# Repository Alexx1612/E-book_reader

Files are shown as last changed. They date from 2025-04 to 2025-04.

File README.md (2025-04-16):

## OPENBOOK E-BOOK READER
OpenBook – Proiect TSC 2025
OpenBook este un prototip de eBook reader open-source, dezvoltat în jurul microcontrolerului ESP32-C6. Dispozitivul este echipat cu un afișaj E-Ink, baterie Li-Po, încărcare prin USB-C, slot pentru card microSD și o serie de senzori de mediu. Proiectul a presupus realizarea completă a schemei electrice, proiectarea plăcii PCB, modelarea 3D și generarea fișierelor pentru fabricație.

## Diagrama bloc
Diagrama

### Caracteristici Cheie
- **Alimentare prin USB-C**  
  Permite programarea ușoară și încărcarea bateriei, asigurând o integrare simplificată cu sursa de alimentare.
- **Microcontroller ESP32-C6**  
  Dispune de un nucleu RISC-V, Wi-Fi 6, BLE și 8MB memorie flash internă pentru aplicații complexe și conectivitate modernă.
- **Senzori Integrați**  
  - **BME688:** Măsoară temperatura, umiditatea, presiunea și concentrațiile de gaze.  
  - **DS3231:** Modul RTC de înaltă precizie, care menține ceasul de timp real chiar și în absența alimentării principale.
- **Stocare Suplimentară**  
  - **Card SD (SPI):** Permite stocarea locală a e-book-urilor și datelor adiționale.  
  - **Memorie NOR Flash (W25Q512):** Oferă spațiu suplimentar de stocare prin interfața SPI.
- **Afișaj E-Paper**  
  Realizează afișajul e-book-urilor cu consum ultra-redus, prin actualizări doar la nevoie.
- **Monitorizare Baterie**  
  Modulul MAX17048 monitorizează nivelul de încărcare al bateriei, contribuind la gestionarea eficientă a consumului de energie.

## Bill of materials (BOM)

| Component | Supplier Link | Datasheet |
|---|---|---|
| XC6220A331MR-G | [Model](https://componentsearchengine.com/part-view/XC6220A331MR-G/Torex) | [Datasheet](https://product.torexsemi.com/system/files/series/xc6220.pdf) |
| W25Q512JVEIQ | [Model](https://www.snapeda.com/parts/W25Q512JVEIQ/Winbond+Electronics/view-part/?ref=eda) | [Datasheet](https://www.winbond.com/resource-files/W25Q512JV%20SPI%20RevB%2006252019%20KMS.pdf) |
| USBLC6-2SC6Y | [Model](https://www.snapeda.com/parts/USBLC6-2SC6Y/STMicroelectronics/view-part/?welcome=home&ref=eda) | [Datasheet](https://www.snapeda.com/parts/USBLC6-2SC6Y/STMicroelectronics/datasheet/) |
| USB4110-GF-A | [Model](https://componentsearchengine.com/part-view/USB4110-GF-A/GCT%20(GLOBAL%20CONNECTOR%20TECHNOLOGY)) | [Datasheet](https://gct.co/files/drawings/usb4110.pdf) |
| SJ | [Model](https://grabcad.com/library/solder-jumpers-1) | [Datasheet]() |
| SI1308EDL-T1-GE3 MOSFET | [Model](https://www.snapeda.com/parts/SI1308EDL-T1-GE3/Vishay+Siliconix/view-part/?welcome=home&ref=eda) | [Datasheet](https://www.snapeda.com/parts/SI1308EDL-T1-GE3/Vishay%20Siliconix/datasheet/) |
| Resistor 0402 | [Model](https://grabcad.com/library/resistor-0402-1) | [Datasheet](https://www.yageo.com/upload/media/product/products/datasheet/rchip/PYu-RC_Group_51_RoHS_L_12.pdf) |
| RCL CPOL 3528 | [Model](https://www.snapeda.com/parts/CPH3225A/Seiko+Instruments/view-part/?ref=eda) | [Datasheet](https://s3.amazonaws.com/snapeda/datasheet/TAJB475K025RNJ_AVX.pdf) |
| QWIIC Connector | [Model](https://www.snapeda.com/parts/PRT-14417/SparkFun/view-part/) | [Datasheet](https://www.snapeda.com/parts/PRT-14417/SparkFun%20Electronics/datasheet/) |
| PGB1010603MR | [Model](https://www.snapeda.com/parts/PGB1010603MR/Littelfuse/view-part/?ref=eda) | [Datasheet](https://www.snapeda.com/parts/PGB1010603MR/Littelfuse%20Inc./datasheet/) |
| MBR0530 Schottky Diode | [Model](https://www.snapeda.com/parts/MBR0530/Onsemi/view-part/?ref=snap) | [Datasheet](https://www.snapeda.com/parts/MBR0530/ON%20Semiconductor/datasheet/) |
| MAX17048G+T10 | [Model](https://www.snapeda.com/parts/MAX17048G+T10/Analog+Devices/view-part/?ref=eda) | [Datasheet](https://www.snapeda.com/parts/MAX17048G+T10/Analog%20Devices/datasheet/) |
| LED Chip 0603 | [Model](https://www.snapeda.com/parts/KP-1608SURCK/Kingbright/view-part/?ref=search&t=LED%200603) | [Datasheet](https://www.snapeda.com/parts/KP-1608SURCK/Kingbright/datasheet/) |
| FH34SRJ-24S-0.5SH | [Model](https://ro.mouser.com/ProductDetail/Hirose-Connector/FH34SRJ-24S-0.5SH99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) | [Datasheet](https://www.snapeda.com/parts/FH34SRJ-24S-0.5SH(99)/Hirose%20Connector/datasheet/) |
| ESP32C6 WROOM-1-N8 | [Model](https://www.snapeda.com/parts/ESP32-C6-WROOM-1-N8/Espressif+Systems/view-part/?ref=eda) | [Datasheet](https://www.snapeda.com/parts/ESP32-C6-WROOM-1-N8/Espressif%20Systems/datasheet/) |
| ESP32C6 Varistor 1812 | [Model]() | [Datasheet]() |
| ESP32 WROVER MCP73831 Power Management | [Model](https://www.snapeda.com/parts/BME680/Bosch/view-part/?welcome=home) | [Datasheet](https://www.snapeda.com/parts/MCP73831T-2ACI/OT/Microchip/datasheet/) |
| ESP32 WROVER BME680 Sensor | [Model](https://www.snapeda.com/parts/BME680/Bosch/view-part/?welcome=home) | [Datasheet](https://www.bosch-sensortec.com/media/boschsensortec/downloads/datasheets/bst-bme680-ds001.pdf) |
| ESP32 WROVER 0805 Capacitor | [Model]() | [Datasheet]() |
| DS3231SN | [Model](https://www.snapeda.com/parts/DS3231SN%23/Analog+Devices/view-part/?ref=eda) | [Datasheet](https://www.snapeda.com/parts/DS3231SN%23/Analog%20Devices/datasheet/) |
| Custom Button | [Model](https://industry.panasonic.com/global/en/products/control/switch/light-touch/number/evqpuj02k) | [Datasheet](https://industry.panasonic.com/global/en/downloads?tab=catalog&small_g_cd=203&part_no=EVQPUJ02K) |
| CPH3225A | [Model](https://www.snapeda.com/parts/CPH3225A/Seiko+Instruments/view-part/?ref=snap) | [Datasheet](https://www.snapeda.com/parts/CPH3225A/Seiko%20Instruments/datasheet/) |
| Capacitor 0402 | [Model](https://ro.mouser.com/c/passive-components/capacitors/ceramic-capacitors/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) | [Datasheet](https://componentsearchengine.com/Datasheets/2/CC0402MRX5R5BB106.pdf) |
| BD5229G-TR | [Model](https://componentsearchengine.com/part-view/BD5229G-TR/ROHM%20Semiconductor) | [Datasheet](https://fscdn.rohm.com/en/products/databook/datasheet/ic/power/voltage_detector/bd52xxg-e.pdf) |
| 744043680 | [Model](https://ro.mouser.com/ProductDetail/Wurth-Elektronik/744043680?qs=PGXP4M47uW6VkZq%252BkzjrHA%3D%3D) | [Datasheet](https://www.we-online.com/components/products/datasheet/744043680.pdf) |
| 112A-TAAR-R03 | [Model](https://store.comet.srl.ro/Catalogue/Product/43497/) | [Datasheet](https://www.snapeda.com/parts/112A-TAAR-R03/Attend/datasheet/) |

## Consum

| Component | Current Draw (mA) | Voltage (V) | Power (mW) |
|---|---|---|---|
| ESP32-C6 (Wi-Fi active) | 200 | 3.3 | 660 |
| E-Paper Display (Updating) | 40 | 3.3 | 132 |
| BME688 Sensor (Measuring) | 3.1 | 3.3 | 10.23 |
| RTC Module (Active) | 0.15 | 3.3 | 0.495 |
| SD Card (Active) | 50 | 3.3 | 165 |
| Externar NOR Flash | 25 | 3.3 | 82.5 |
| **Total Estimated Power Consumption** | ~318.5 mA | 3.3 | 1050.72 |

### Arhitectura Hardware
- **Alimentare și Protecție:**  
  Sistemul beneficiază de alimentare prin USB-C și include protecții ESD (varistori, diodă TVS) pentru siguranța componentelor. Circuitul de încărcare Li-Po (MCP73831) și regulatorul LDO asigură o tensiune stabilă de 3.3V.
- **Conectivitate și Interfețe:**  
  Microcontrollerul ESP32-C6-WROOM-1 acționează ca nucleu central, conectând diferite periferice prin:
  - **SPI:** Utilizat pentru afișajul E-Paper, Cardul SD și memoria NOR Flash.  
  - **I2C:** Folosit pentru senzorii BME688 și DS3231, precum și pentru monitorizarea bateriei.  
  - **GPIO:** Gestionarea butoanelor de control (RESET, BOOT) și alte funcții digitale.

### Mapare Pini ESP32-C6
| Component | ESP32-C6 Pin(s) | Interface | Scop |
|---|---|---|---|
| **E-Paper Display** | IO7 (MOSI), IO6 (SCK), IO10 (CS), IO5 (DC), IO23 (RST), IO3 (BUSY) | SPI | Transferă datele imaginii către afișaj și controlează starea acestuia. |
| **Battery Monitoring (MAX17048)** | IO21 (SDA), IO22 (SCL) | I2C | Monitorizează tensiunea bateriei și starea de încărcare pentru un management energetic eficient. |
| **USB-C Connection** | GPIOs prin circuit de protecție și reglementare | USB | Furnizează alimentarea și permite programarea ESP32-C6. 
| **MicroSD Card** | IO7 (MOSI), IO6 (SCK), IO4 (SS_SD), IO2 (MISO) | SPI | Permite stocarea și accesarea fișierelor de e-book. |
| **Environmental Sensor (BME688)** | IO21 (SDA), IO22 (SCL) | I2C | Măsoară temperatura, umiditatea, presiunea și calitatea aerului. |
| **RTC Module (DS3231)** | IO21 (SDA), IO22 (SCL), IO18 (RST), IO1 (32KHz), IO0 (INT_RTC) | I2C | Menține ceasul de timp real în mod precis, chiar și în absența alimentării principale. |
| **External NOR Flash** | IO11 (CS), IO6 (SCK), IO2 (MISO), IO7 (MOSI) | SPI | Oferă stocare suplimentară pentru datele aplicațiilor și firmware. |
| **Control Buttons** | IO9 (BOOT), IO15 (CHANGE), EN (RESET) | GPIO | Permite interacțiunea utilizatorului prin funcții de boot, reset și alte comenzi digitale.| 

## Observații Suplimentare

- Traseele de alimentare au o lățime de 0.3 mm, iar traseele de semnal sunt proiectate cu o lățime de 0.15 mm, pentru a asigura o transmisie clară și o pierdere minimă de semnal.
- PCB-ul are o grosime de 1 mm și include planuri de masă pe ambele straturi, pentru a optimiza împământarea și a reduce interferențele electromagnetice.
- Conectorii, afișajul E-Paper și bateria au fost integrate în modelul 3D, iar acestea au fost testate riguros pentru a asigura o potrivire perfectă în carcasă.
- Carcasa a fost importată și aliniată cu placa pentru a obține render-uri vizuale realiste, facilitând astfel evaluarea designului final.
- Toate fișierele de proiect au fost verificate prin ERC (Electrical Rules Check) și DRC (Design Rules Check) pentru a asigura conformitatea cu standardele de proiectare și a elimina eventualele erori de fabricație.

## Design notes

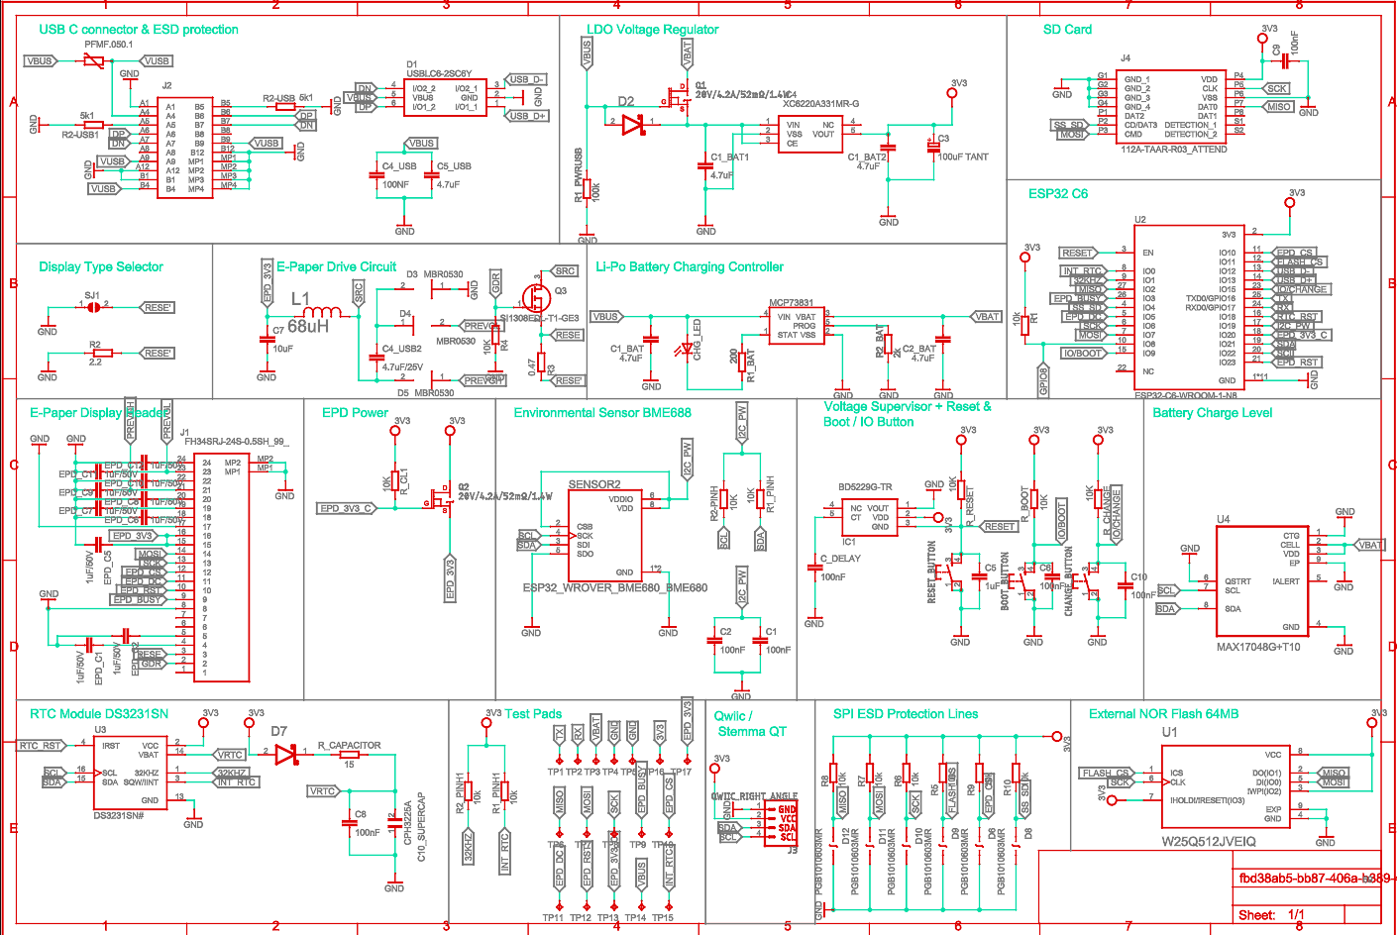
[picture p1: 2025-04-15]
Images/Schematic.png

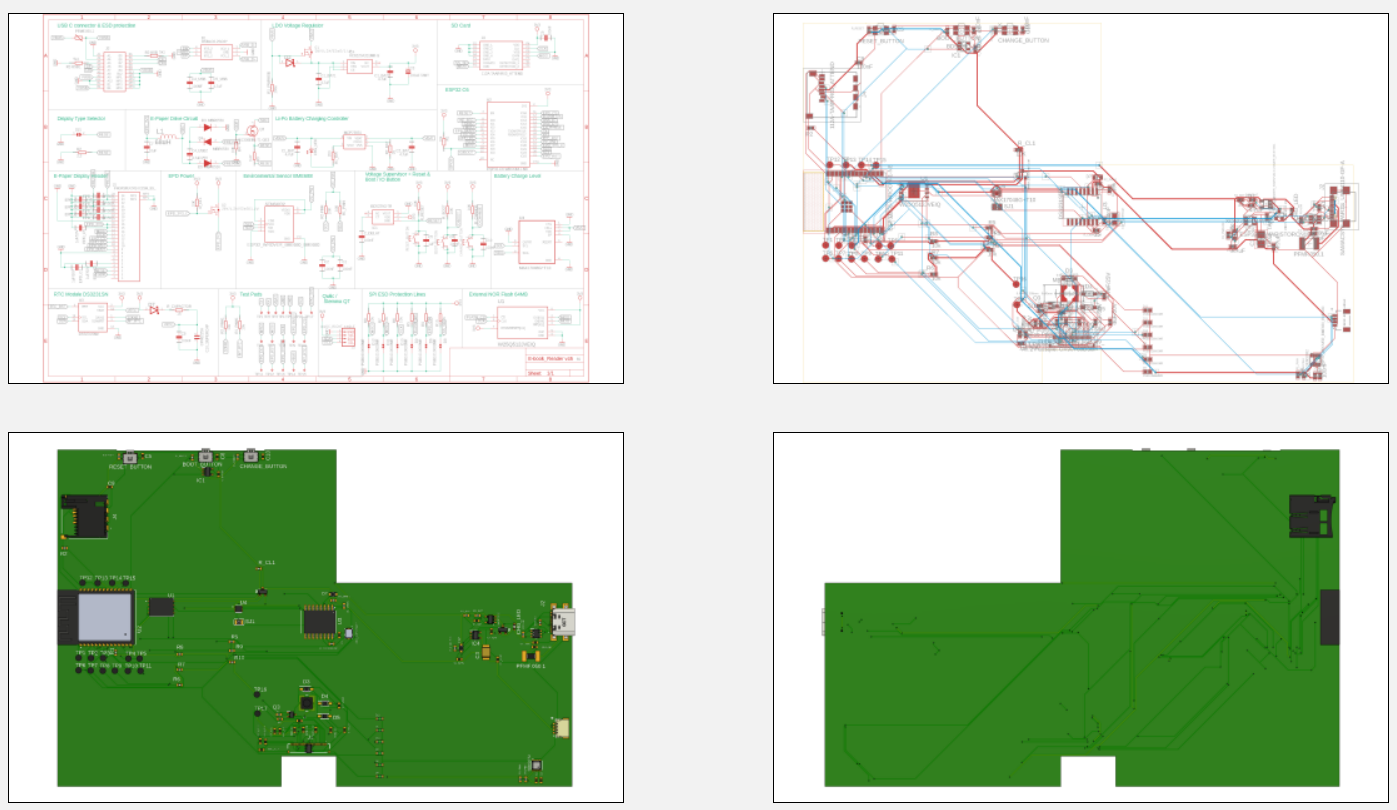
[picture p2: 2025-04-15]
Images/project.png

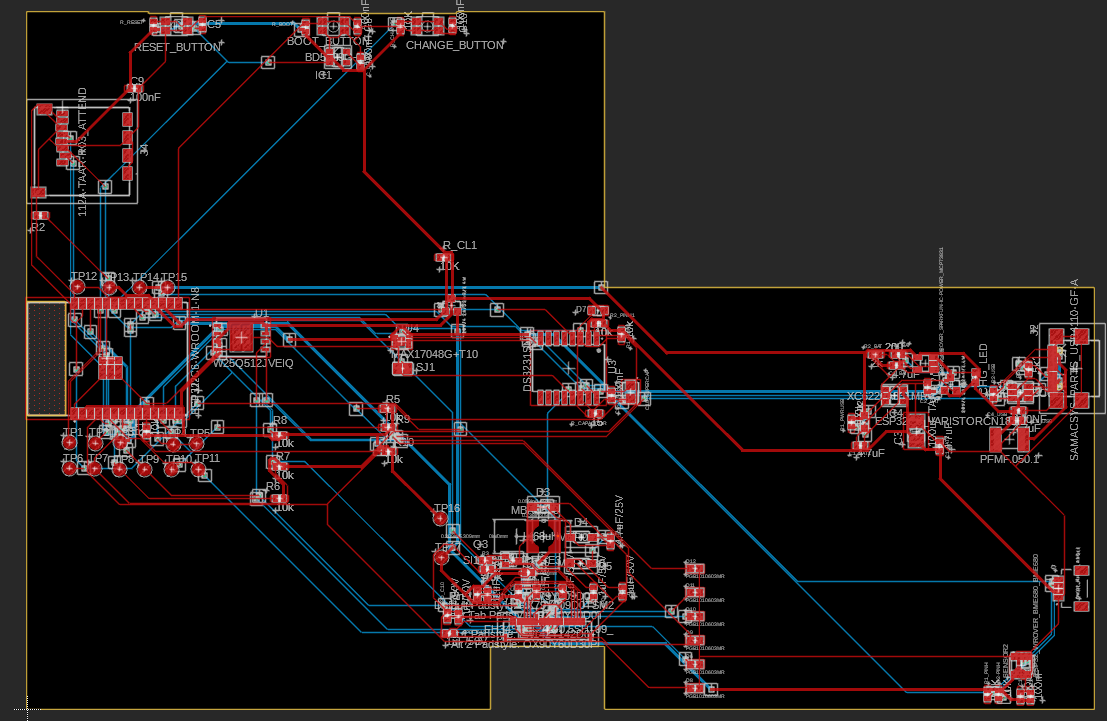
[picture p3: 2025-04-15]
Images/PCB_2D.png

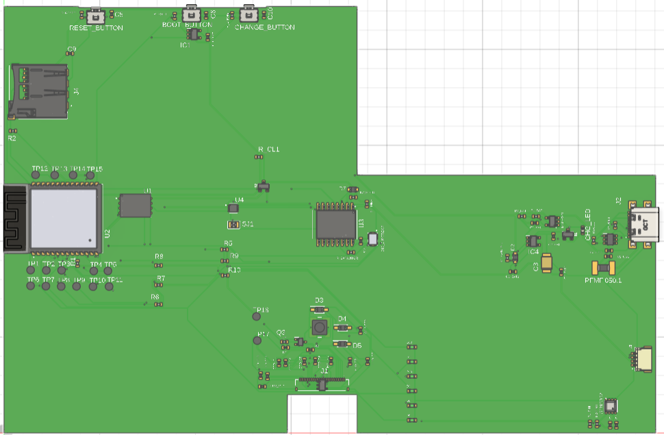
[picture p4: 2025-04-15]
Images/PCB_3D_top.png

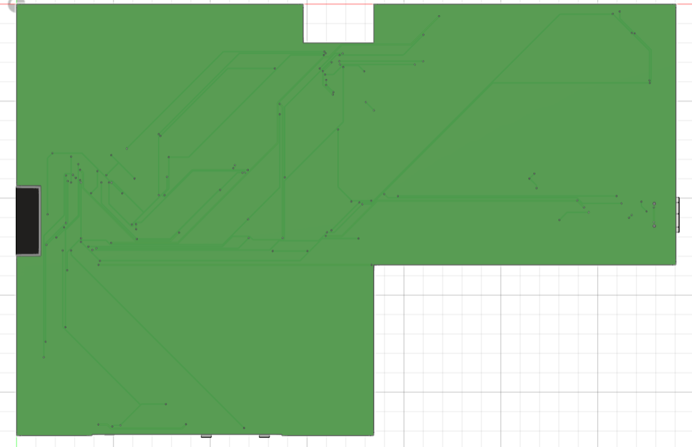
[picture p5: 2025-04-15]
Images/PCB_3D_bottom.png

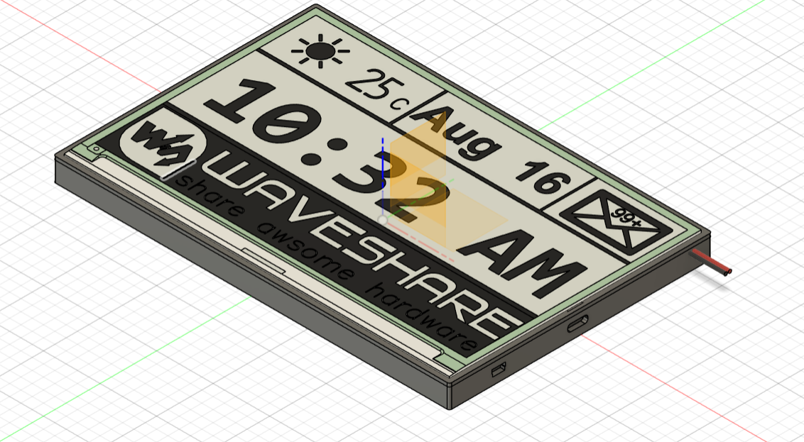
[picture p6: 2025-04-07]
Images/PCB_3D_enclosed.png

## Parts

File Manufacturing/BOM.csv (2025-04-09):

Qty | Value | Device | Package | Parts | Description | ARROW_PART_NUMBER | ARROW_PRICE-STOCK | AVAILABILITY | CENTROID_NOT_SPECIFIED | CHECK_PRICES | COPYRIGHT | DATASHEET | DESCRIPTION | DIGIKEY_DESCRIPTION | DIGIKEY_PART_NUMBER | HEIGHT | LEAD_FREE | MANUFACTURER_NAME | MANUFACTURER_PART_NUMBER | MF | MFR_NAME | MOUSER_PART_NUMBER | MOUSER_PRICE-STOCK | MOUSER_TESTING_PART_NUMBER | MOUSER_TESTING_PRICE-STOCK | MP | MPN | PACKAGE | POPULARITY | PREFIX | PRICE | PROD_ID | PURCHASE-URL | ROHS | SNAPEDA_LINK | SPICEMODEL | SPICEPREFIX | TEMPERATURE_RANGE_HIGH | TEMPERATURE_RANGE_LOW | TP_SIGNAL_NAME | VALUE
1 |  | ADAFRUIT_LEDCHIP-LED0603 | ADAFRUIT_CHIP-LED0603 | CHG_LED | LED
1 |  | SJ | SJ | SJ1 | SMD solder JUMPER |  |  |  |  |  |  |  |  |  |  |  |  |  |  |  |  |  |  |  |  |  |  |  | 3
1 | 0.47 | ESP32_WROVER_EAGLE-LTSPICE_RR0402 | ESP32_WROVER_EAGLE-LTSPICE_R0402 | R3 | RESISTOR, European symbol |  |  |  |  |  |  |  |  |  |  |  |  |  |  |  |  |  |  |  |  |  |  |  |  |  |  |  |  |  |  | NONE | R
1 | 100NF | EAGLE-LTSPICE_CC0402 | EAGLE-LTSPICE_C0402 | C4_USB | CAPACITOR, European symbol |  |  |  |  |  |  |  |  |  |  |  |  |  |  |  |  |  |  |  |  |  |  |  |  |  |  |  |  |  |  | NONE | C
1 | 100k | ESP32_WROVER_EAGLE-LTSPICE_RR0402 | ESP32_WROVER_EAGLE-LTSPICE_R0402 | R1_PWRUSB | RESISTOR, European symbol |  |  |  |  |  |  |  |  |  |  |  |  |  |  |  |  |  |  |  |  |  |  |  |  |  |  |  |  |  |  | NONE | R
7 | 100nF | EAGLE-LTSPICE_CC0402 | EAGLE-LTSPICE_C0402 | C1, C2, C6, C8, C9, C10, C_DELAY | CAPACITOR, European symbol |  |  |  |  |  |  |  |  |  |  |  |  |  |  |  |  |  |  |  |  |  |  |  |  |  |  |  |  |  |  | NONE | C
1 | 100uF TANT | RCL_CPOL-EUCT3528 | RCL_CT3528 | C3 | POLARIZED CAPACITOR, European symbol |  |  |  |  |  |  |  |  |  |  |  |  |  |  |  |  |  |  |  |  |  |  |  | 0 |  |  |  |  |  |  |  | C
7 | 10K | ESP32_WROVER_EAGLE-LTSPICE_RR0402 | ESP32_WROVER_EAGLE-LTSPICE_R0402 | R1_PINH, R2-PINH, R4, R_BOOT, R_CHANGE, R_CL1, R_RESET | RESISTOR, European symbol |  |  |  |  |  |  |  |  |  |  |  |  |  |  |  |  |  |  |  |  |  |  |  |  |  |  |  |  |  |  | NONE | R
9 | 10k | ESP32_WROVER_EAGLE-LTSPICE_RR0402 | ESP32_WROVER_EAGLE-LTSPICE_R0402 | R1_PINH1, R2_PINH1, R2_PINH5, R5, R6, R7, R8, R9, R10 | RESISTOR, European symbol |  |  |  |  |  |  |  |  |  |  |  |  |  |  |  |  |  |  |  |  |  |  |  |  |  |  |  |  |  |  | NONE | R
1 | 10uF | EAGLE-LTSPICE_CC0402 | EAGLE-LTSPICE_C0402 | C7 | CAPACITOR, European symbol |  |  |  |  |  |  |  |  |  |  |  |  |  |  |  |  |  |  |  |  |  |  |  |  |  |  |  |  |  |  | NONE | C
1 | 112A-TAAR-R03_ATTEND | 112A-TAAR-R03_ATTEND | 112ATAARR03ATTEND | J4 | Micro SD Card Socket, Push-Push Type, Top Mount, SMT, H=1.83mm, 10u |  |  |  |  |  |  |  | Micro SD Card Socket | Push-Push Type | Top Mount | SMT | H=1.83mm | 10u |  |  | 1.9mm |  | ATTEND | 112A-TAAR-R03 ATTEND
1 | 15 | ESP32_WROVER_EAGLE-LTSPICE_RR0402 | ESP32_WROVER_EAGLE-LTSPICE_R0402 | R_CAPACITOR | RESISTOR, European symbol |  |  |  |  |  |  |  |  |  |  |  |  |  |  |  |  |  |  |  |  |  |  |  |  |  |  |  |  |  |  | NONE | R
1 | 1uF | EAGLE-LTSPICE_CC0402 | EAGLE-LTSPICE_C0402 | C5 | CAPACITOR, European symbol |  |  |  |  |  |  |  |  |  |  |  |  |  |  |  |  |  |  |  |  |  |  |  |  |  |  |  |  |  |  | NONE | C
10 | 1uF/50V | EAGLE-LTSPICE_CC0402 | EAGLE-LTSPICE_C0402 | EPD_C1, EPD_C2, EPD_C5, EPD_C6, EPD_C7, EPD_C8, EPD_C9, EPD_C10, EPD_C11, EPD_C12 | CAPACITOR, European symbol |  |  |  |  |  |  |  |  |  |  |  |  |  |  |  |  |  |  |  |  |  |  |  |  |  |  |  |  |  |  | NONE | C
1 | 2.2 | ESP32_WROVER_EAGLE-LTSPICE_RR0402 | ESP32_WROVER_EAGLE-LTSPICE_R0402 | R2 | RESISTOR, European symbol |  |  |  |  |  |  |  |  |  |  |  |  |  |  |  |  |  |  |  |  |  |  |  |  |  |  |  |  |  |  | NONE | R
1 | 200 | ESP32_WROVER_EAGLE-LTSPICE_RR0402 | ESP32_WROVER_EAGLE-LTSPICE_R0402 | R1_BAT | RESISTOR, European symbol |  |  |  |  |  |  |  |  |  |  |  |  |  |  |  |  |  |  |  |  |  |  |  |  |  |  |  |  |  |  | NONE | R
2 | 20V/4.2A/52mO/1.4W | ESP32_WROVER_SPARKFUN-DISCRETESEMI_MOSFET_PCH-DMG2305UX-7 | ESP32_WROVER_SPARKFUN-DISCRETESEMI_SOT23-3 | Q1, Q2 | P-channel MOSFETs |  |  |  |  |  |  |  |  |  |  |  |  |  |  |  |  |  |  |  |  |  |  |  |  |  |  | TRAN-14388 |  |  |  |  |  |  |  |  | 20V/4.2A/52mO/1.4W
1 | 2k | ESP32_WROVER_EAGLE-LTSPICE_RR0402 | ESP32_WROVER_EAGLE-LTSPICE_R0402 | R2_BAT | RESISTOR, European symbol |  |  |  |  |  |  |  |  |  |  |  |  |  |  |  |  |  |  |  |  |  |  |  |  |  |  |  |  |  |  | NONE | R
5 | 4.7uF | EAGLE-LTSPICE_CC0402 | EAGLE-LTSPICE_C0402 | C1_BAT, C1_BAT1, C1_BAT2, C2_BAT, C5_USB | CAPACITOR, European symbol |  |  |  |  |  |  |  |  |  |  |  |  |  |  |  |  |  |  |  |  |  |  |  |  |  |  |  |  |  |  | NONE | C
1 | 4.7uF/25V | EAGLE-LTSPICE_CC0402 | EAGLE-LTSPICE_C0402 | C4_USB2 | CAPACITOR, European symbol |  |  |  |  |  |  |  |  |  |  |  |  |  |  |  |  |  |  |  |  |  |  |  |  |  |  |  |  |  |  | NONE | C
2 | 5k1 | ESP32_WROVER_EAGLE-LTSPICE_RR0402 | ESP32_WROVER_EAGLE-LTSPICE_R0402 | R2-USB, R2-USB1 | RESISTOR, European symbol |  |  |  |  |  |  |  |  |  |  |  |  |  |  |  |  |  |  |  |  |  |  |  |  |  |  |  |  |  |  | NONE | R
1 | 68uH | 744043680IND_4828-WE-TPC_WRE | IND_4828-WE-TPC_WRE | L1 |  |  |  |  |  |  | Copyright (C) 2024 Ultra Librarian. All rights reserved. |  |  |  |  |  |  |  | 744043680 |  | Wurth Electronics
1 | BD5229G-TR | BD5229G-TR | SOT95P280X125-5N | IC1 | Voltage Detector with Adjustable Delay Time: CMOS processes are utilized to develop high precision, low current consumption CMOS reset ICs that allow arbitrary setting of the delay time. The extensive lineup includes both Nch Open Drain and CMOS output types in a wide range of detection voltages (from 2.3V to 6.0V, in 0.1V steps), enabling selection of the ideal solution based on customer requirements. In addition, the entire series is of course both lead-free and RoHS-compliant. |  |  |  |  |  |  |  | Voltage Detector with Adjustable Delay Time: CMOS processes are utilized to develop high precision | low current consumption CMOS reset ICs that allow arbitrary setting of the delay time. The extensive lineup includes both Nch Open Drain and CMOS output types in a wide range of detection voltages (from 2.3V to 6.0V | in 0.1V steps) | enabling selection of the ideal solution based on customer requirements. In addition | the entire series is of course both lead-free and RoHS-compliant. |  |  | 1.25mm |  | ROHM Semiconductor | BD5229G-TR |  |  | 755-BD5229G-TR | https://www.mouser.co.uk/ProductDetail/ROHM-Semiconductor/BD5229G-TR?qs=4kLU8WoGk0vvnhrrYwdszw%3D%3D
3 | BUTTON_CUSYOMV1 | BUTTON_CUSYOMV1 | MYBUTTON | BOOT_BUTTON, CHANGE_BUTTON, RESET_BUTTON
1 | CPH3225A | CPH3225A | CAPCP3225X100N | C10_SUPERCAP | Cap 0.011F 3.3V 1210 Flat Check availability |  |  | Not in stock |  | https://www.snapeda.com/parts/CPH3225A/Seiko+Instruments/view-part/?ref=eda |  |  | 11 mF (EDLC) Supercapacitor 3.3 V 1210 (3225 Metric) - - |  |  |  |  |  |  | Seiko Instruments |  |  |  |  |  | CPH3225A |  | 1210 Seiko |  |  | None |  | https://www.snapeda.com/api/url_track_click_mouser/?unipart_id=562593&manufacturer=Seiko Instruments&part_name=CPH3225A&search_term=None |  | https://www.snapeda.com/parts/CPH3225A/Seiko+Instruments/view-part/?ref=snap
1 | DS3231SN# | DS3231SN# | SOIC127P1032X265-16N | U3 | Real Time Clock Serial 16-Pin SOIC W T/R Check availability |  |  | In Stock |  | https://www.snapeda.com/parts/DS3231SN%23/Analog+Devices/view-part/?ref=eda |  |  | Extremely Accurate I²C-Integrated RTC/TCXO/Crystal |  |  |  |  |  |  | Analog Devices |  |  |  |  |  | DS3231SN# |  | SOIC-16 Maxim |  |  | None |  | https://www.snapeda.com/api/url_track_click_mouser/?unipart_id=99048&manufacturer=Analog Devices&part_name=DS3231SN#&search_term=None |  | https://www.snapeda.com/parts/DS3231SN%23/Analog+Devices/view-part/?ref=snap
1 | ESP32-C6-WROOM-1-N8 | ESP32-C6-WROOM-1-N8 | XCVR_ESP32-C6-WROOM-1-N8 | U2 | Check availability |  |  | In Stock |  | https://www.snapeda.com/parts/ESP32-C6-WROOM-1-N8/Espressif+Systems/view-part/?ref=eda |  |  | Multiprotocol Modules ESP32-C6 module | Wi-Fi 6 in 2.4 GHz band | Bluetooth 5 | Zigbee 3.0 and Thread. ESP34-WROOM Compatible - ENGINEERING SAMPLE |  |  |  |  |  |  | Espressif Systems |  |  |  |  |  | ESP32-C6-WROOM-1-N8 |  | None |  |  | None |  |  |  | https://www.snapeda.com/parts/ESP32-C6-WROOM-1-N8/Espressif+Systems/view-part/?ref=snap
1 | ESP32C6_VARISTORCN1812 | ESP32C6_VARISTORCN1812 | ESP32C6_VARISTOR_CT/CN1812 | PFMF.050.1 | VARISTOR |  |  |  |  |  |  |  |  |  |  |  |  |  |  |  |  |  |  |  |  |  |  |  | 0
2 | ESP32_WROVER_AVX---SD0805S020S1R0_AVX_SD0805S020S1R0_0_0AVX_SD0805S020S1R0_0_0 | ESP32_WROVER_AVX---SD0805S020S1R0_AVX_SD0805S020S1R0_0_0AVX_SD0805S020S1R0_0_0 | ESP32_WROVER_AVX---SD0805S020S1R0_AVX_SD0805S020S1R0_0 | D2, D7 | Schottky Barrier Rectifier Diode |  |  |  | No |  |  | http://datasheets.avx.com/schottky.pdf |  | DIODE SCHOTTKY 20V 1A 0805 | 478-7800-1-ND |  | yes |  |  | AVX |  | 581-SD0805S020S1R0 |  |  |  |  |  | 0805 (2012 metric) |  | D |  |  |  | yes |  |  |  | +125°C | -55°C
1 | ESP32_WROVER_BME680_BME680 | ESP32_WROVER_BME680_BME680 | ESP32_WROVER_BME680_PSON80P300X300X100-8N | SENSOR2 | Integrated Environmental Unit |  |  | Unavailable |  |  |  |  | Integrated Environmental Unit |  |  |  |  |  |  | Bosch Sensortec |  |  |  |  |  | BME680 |  | LGA-8 Bosch Tools |  |  | None
1 | ESP32_WROVER_SPARKFUN-IC-POWER_MCP73831 | ESP32_WROVER_SPARKFUN-IC-POWER_MCP73831 | ESP32_WROVER_SPARKFUN-IC-POWER_SOT23-5 | MCP73831 | MCP73831T Li-Ion, Li-Pol Controller |  |  |  |  |  |  |  |  |  |  |  |  |  |  |  |  |  |  |  |  |  |  |  |  |  |  | IC-09995
1 | FH34SRJ-24S-0.5SH_99_ | FH34SRJ-24S-0.5SH_99_ | FH34SRJ24S05SH99 | J1 | (0.50mm) Surface Mount, Right Angle |  |  |  |  |  |  |  | 24 Position FFC | FPC Connector Contacts | (0.50mm) Surface Mount | Right Angle |  |  | 1.1mm |  | Hirose | FH34SRJ-24S-0.5SH(99) |  |  | 798-FH34SRJ24S05SH99 | https://www.mouser.co.uk/ProductDetail/Hirose-Connector/FH34SRJ-24S-0.5SH99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
1 | MAX17048G+T10 | MAX17048G+T10 | SON50P200X200X80-9N | U4 | Check availability |  |  | In Stock |  | https://www.snapeda.com/parts/MAX17048G+T10/Analog+Devices/view-part/?ref=eda |  |  | 3µA 1-Cell/2-Cell Fuel Gauge with ModelGauge |  |  |  |  |  |  | Analog Devices |  |  |  |  |  | MAX17048G+T10 |  | TDFN-8 Maxim |  |  | None |  | https://www.snapeda.com/api/url_track_click_mouser/?unipart_id=329239&manufacturer=Analog Devices&part_name=MAX17048G+T10&search_term=None |  | https://www.snapeda.com/parts/MAX17048G+T10/Analog+Devices/view-part/?ref=snap
3 | MBR0530 | MBR0530 | SOD3716X135N | D3, D4, D5 | ON SEMICONDUCTOR - MBR0530 - DIODE, SCHOTTKY, 0.5A, 30V, SOD-123 |  |  | In Stock |  | https://www.snapeda.com/parts/MBR0530/Onsemi/view-part/?ref=eda |  |  | Diode Schottky 30 V 500mA Surface Mount SOD-123 |  |  |  |  |  |  | ON Semiconductor |  |  |  |  |  | MBR0530 |  | SOD-123-2 ON Semiconductor |  |  | None |  | https://www.snapeda.com/api/url_track_click_mouser/?unipart_id=179458&manufacturer=ON Semiconductor&part_name=MBR0530&search_term=None |  | https://www.snapeda.com/parts/MBR0530/Onsemi/view-part/?ref=snap
6 | PGB1010603MR | PGB1010603MR | DIOC1608X36N | D6, D8, D9, D10, D11, D12 | Check availability |  |  | In Stock |  | https://www.snapeda.com/parts/PGB1010603MR/Littelfuse/view-part/?ref=eda |  |  | 150V (Typ) Clamp - Ipp Tvs Diode Surface Mount 0603 (1608 Metric) |  |  |  |  |  |  | Littelfuse Inc. |  |  |  |  |  | PGB1010603MR |  | 0603 Littelfuse Inc. |  |  | None |  | https://www.snapeda.com/api/url_track_click_mouser/?unipart_id=5659453&manufacturer=Littelfuse Inc.&part_name=PGB1010603MR&search_term=None |  | https://www.snapeda.com/parts/PGB1010603MR/Littelfuse/view-part/?ref=snap
1 | QWIIC_RIGHT_ANGLE | QWIIC_CONNECTORJS-1MM | JST04_1MM_RA | J3 | SparkFun I2C Standard Qwiic Connector |  |  |  |  |  |  |  |  |  |  |  |  |  |  |  |  |  |  |  |  |  |  |  |  |  |  | CONN-13694 |  |  |  |  |  |  |  |  | QWIIC_RIGHT_ANGLE
1 | SAMACSYS_PARTS_USB4110-GF-A | SAMACSYS_PARTS_USB4110-GF-A | SAMACSYS_PARTS_USB4110GFA | J2 | CONN USB 2.0 TYPE-C R/A SMT |  |  |  |  |  |  |  | CONN USB 2.0 TYPE-C R/A SMT |  |  | 3.26mm |  | GCT (GLOBAL CONNECTOR TECHNOLOGY) | USB4110-GF-A |  |  | 640-USB4110-GF-A | https://www.mouser.co.uk/ProductDetail/GCT/USB4110-GF-A?qs=KUoIvG%2F9IlYiZvIXQjyJeA%3D%3D
1 | SI1308EDL-T1-GE3 | SI1308EDL-T1-GE3 | SOT65P210X110-3N | Q3 | MOSFET N-Ch 30V 1.5A TrenchFET SC70 Vishay Si1308EDL-T1-GE3 N-channel MOSFET Transistor, 1.5 A, 30 V, 3-Pin SC-70 |  |  | In Stock |  | https://www.snapeda.com/parts/SI1308EDL-T1-GE3/Vishay+Siliconix/view-part/?ref=eda |  |  | Si1308EDL-T1-GE3 N-channel MOSFET Transistor | 1.5 A | 30 V | 3-Pin SC-70 | Siliconix / Vishay SI1308EDL-T1-GE3 |  |  |  |  |  |  | Vishay Siliconix |  |  |  |  |  | SI1308EDL-T1-GE3 |  | SOT-323 Vishay Semiconductor |  |  | None |  | https://www.snapeda.com/api/url_track_click_mouser/?unipart_id=274603&manufacturer=Vishay Siliconix&part_name=SI1308EDL-T1-GE3&search_term=None |  | https://www.snapeda.com/parts/SI1308EDL-T1-GE3/Vishay+Siliconix/view-part/?ref=snap
17 | TPTP20R | TPTP20R | TP20R | TP1, TP2, TP3, TP4, TP5, TP6, TP7, TP8, TP9, TP10, TP11, TP12, TP13, TP14, TP15, TP16, TP17 | Test pad |  |  |  |  |  |  |  |  |  |  |  |  |  |  |  |  |  |  |  |  |  |  |  | 2
1 | USBLC6-2SC6Y | USBLC6-2SC6Y | SOT95P280X145-6N | D1 | Low Cap. ESD Protection Auto SOT-23-6 STMicroelectronics USBLC6-2SC6Y, Dual Uni-Directional TVS Diode Array, 6-Pin SOT-23 |  |  | In Stock |  | https://www.snapeda.com/parts/USBLC6-2SC6Y/STMicroelectronics/view-part/?ref=eda |  |  | 17V Clamp 5A (8/20µs) Ipp Tvs Diode Surface Mount SOT-23-6 |  |  |  |  |  |  | STMicroelectronics |  |  |  |  |  | USBLC6-2SC6Y |  | SOT-23-6 STMicroelectronics |  |  | None |  |  |  | https://www.snapeda.com/parts/USBLC6-2SC6Y/STMicroelectronics/view-part/?ref=snap
1 | W25Q512JVEIQ | W25Q512JVEIQ | SON127P600X800X80-9N | U1 | Check availability |  |  | In Stock |  | https://www.snapeda.com/parts/W25Q512JVEIQ/Winbond+Electronics/view-part/?ref=eda |  |  | FLASH - NOR Memory IC 512Mb (64M x 8) SPI - Quad I/O 133 MHz 8-WSON (8x6) |  |  |  |  |  |  | Winbond Electronics |  |  |  |  |  | W25Q512JVEIQ |  | Package |  |  | None |  |  |  | https://www.snapeda.com/parts/W25Q512JVEIQ/Winbond+Electronics/view-part/?ref=snap
1 | XC6220A331MR-G | XC6220A331MR-G | SOT95P280X120-5N | IC4 | LDO Voltage Regulators |  |  |  |  |  |  |  | LDO Voltage Regulators |  |  | 1.2mm |  | Torex | XC6220A331MR-G |  |  | 865-XC6220A331MR-G | https://www.mouser.co.uk/ProductDetail/Torex-Semiconductor/XC6220A331MR-G?qs=AsjdqWjXhJ8ZSWznL1J0gg%3D%3D

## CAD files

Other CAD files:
Mechanical/OpenBook+Final.f3z

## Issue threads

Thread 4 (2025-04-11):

Lipsește modelul 3D pentru testpad, iar plasarea acestora este neobișnuită

Victor270104, 2025-04-11:
Am observat că pentru testpad-uri nu există un model 3D în proiect, iar poziționarea lor pe placă este destul de ciudată. Această situație poate îngreuna atât vizualizarea, cât și manufacturarea PCB-ului. Recomand:

Adăugarea sau asocierea unui model 3D pentru testpad-uri, pentru a facilita verificarea design-ului.

Ajustarea plasării testpad-urilor astfel încât să fie accesibile și corect aliniate pe PCB, evitând zonele care pot interfera cu alte componente sau trasee.

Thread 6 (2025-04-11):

Poziționarea antenei ESP32 și decupajul PCB sub antenă

Victor270104, 2025-04-11:
Modulul ESP32 este poziționat cu antena spre exterior – ceea ce este corect – însă lipsește decupajul PCB sub zona antenei. Decupajul ajută la îmbunătățirea semnalului wireless și reduce interferențele, conform recomandărilor de design ESP32. Recomand realizarea acestui slot pentru a maximiza performanța antenei.

Closed 2025-04-15.

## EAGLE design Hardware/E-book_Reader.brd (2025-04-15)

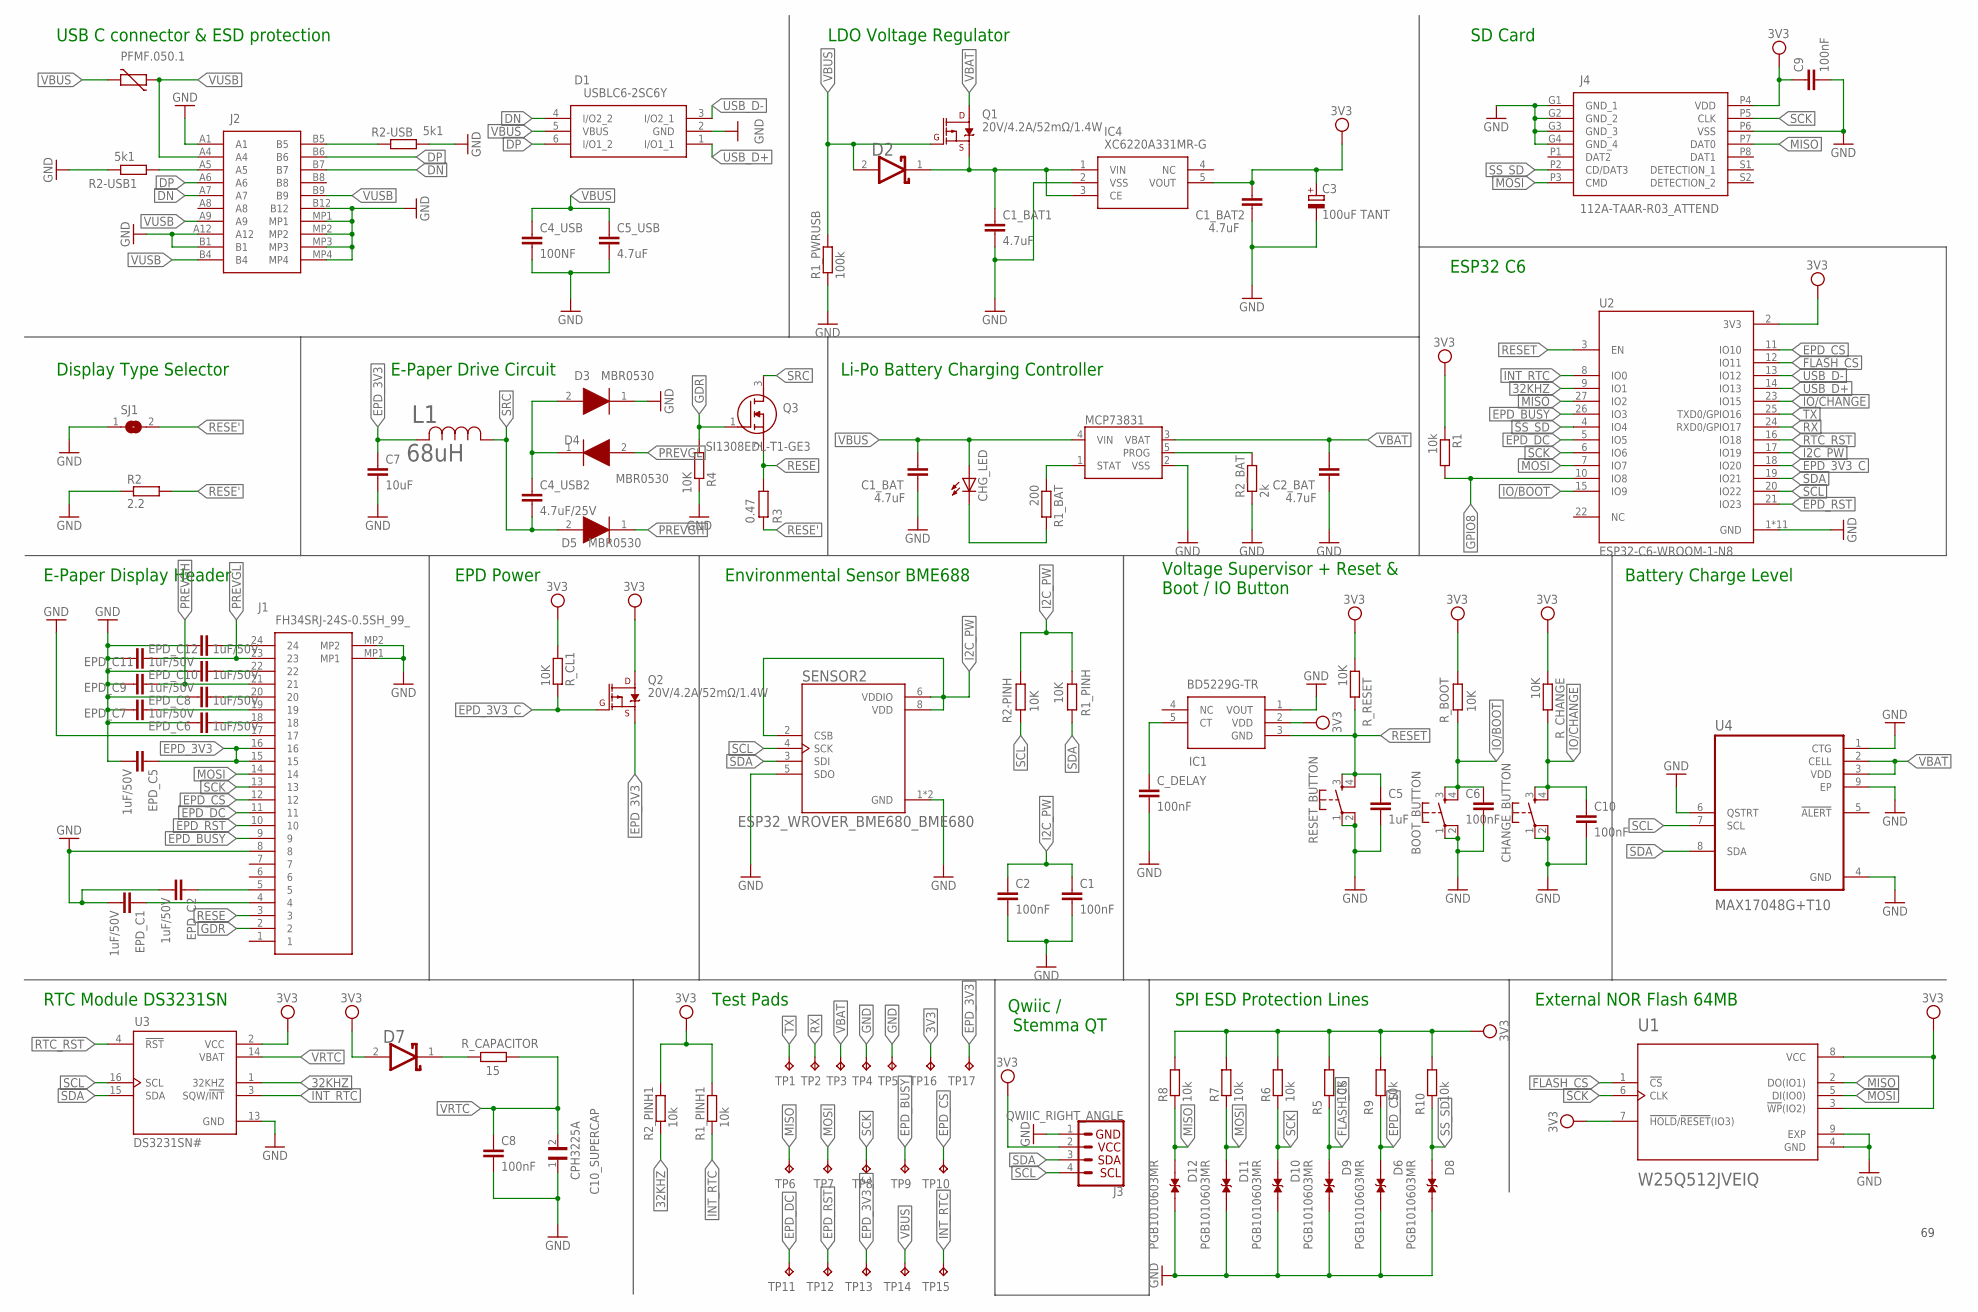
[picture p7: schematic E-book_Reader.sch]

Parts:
BOOT_BUTTON: BUTTON_CUSYOMV1; MYBUTTON
C1, C2, C6, C8, C9, C10: 100nF; EAGLE-LTSPICE_C0402
C1_BAT, C1_BAT1, C1_BAT2, C2_BAT, C5_USB: 4.7uF; EAGLE-LTSPICE_C0402
C3: 100uF TANT; RCL_CT3528
C4_USB: 100NF; EAGLE-LTSPICE_C0402
C4_USB2: 4.7uF/25V; EAGLE-LTSPICE_C0402
C5: 1uF; EAGLE-LTSPICE_C0402
C7: 10uF; EAGLE-LTSPICE_C0402
C10_SUPERCAP: CPH3225A; CAPCP3225X100N
CHANGE_BUTTON: BUTTON_CUSYOMV1; MYBUTTON
CHG_LED: ADAFRUIT_LEDCHIP-LED0603; ADAFRUIT_CHIP-LED0603
C_DELAY: 100nF; EAGLE-LTSPICE_C0402
D1: USBLC6-2SC6Y; SOT95P280X145-6N
D2, D7: ESP32_WROVER_AVX---SD0805S020S1R0_AVX_SD0805S020S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; ESP32_WROVER_AVX---SD0805S020S1R0_AVX_SD0805S020S1R0_0
D3, D4, D5: MBR0530; SOD3716X135N
D6, D8, D9, D10, D11, D12: PGB1010603MR; DIOC1608X36N
EPD_C1, EPD_C2, EPD_C5, EPD_C6, EPD_C7, EPD_C8, EPD_C9, EPD_C10, EPD_C11, EPD_C12: 1uF/50V; EAGLE-LTSPICE_C0402
IC1: BD5229G-TR; SOT95P280X125-5N
IC4: XC6220A331MR-G; SOT95P280X120-5N
J1: FH34SRJ-24S-0.5SH_99_; FH34SRJ24S05SH99
J2: SAMACSYS_PARTS_USB4110-GF-A; SAMACSYS_PARTS_USB4110GFA
J3: QWIIC_RIGHT_ANGLE; JST04_1MM_RA
J4: 112A-TAAR-R03_ATTEND; 112ATAARR03ATTEND
L1: 68uH; IND_4828-WE-TPC_WRE
MCP73831: ESP32_WROVER_SPARKFUN-IC-POWER_MCP73831; ESP32_WROVER_SPARKFUN-IC-POWER_SOT23-5
PFMF.050.1: ESP32C6_VARISTORCN1812; ESP32C6_VARISTOR_CT/CN1812
Q1, Q2: 20V/4.2A/52mΩ/1.4W; ESP32_WROVER_SPARKFUN-DISCRETESEMI_SOT23-3
Q3: SI1308EDL-T1-GE3; SOT65P210X110-3N
R1, R1_PINH1, R2_PINH1, R5, R6, R7, R8, R9, R10: 10k; ESP32_WROVER_EAGLE-LTSPICE_R0402
R1_BAT: 200; ESP32_WROVER_EAGLE-LTSPICE_R0402
R1_PINH, R2-PINH, R4: 10K; ESP32_WROVER_EAGLE-LTSPICE_R0402
R1_PWRUSB: 100k; ESP32_WROVER_EAGLE-LTSPICE_R0402
R2: 2.2; ESP32_WROVER_EAGLE-LTSPICE_R0402
R2-USB, R2-USB1: 5k1; ESP32_WROVER_EAGLE-LTSPICE_R0402
R2_BAT: 2k; ESP32_WROVER_EAGLE-LTSPICE_R0402
R3: 0.47; ESP32_WROVER_EAGLE-LTSPICE_R0402
RESET_BUTTON: BUTTON_CUSYOMV1; MYBUTTON
R_BOOT: 10K; ESP32_WROVER_EAGLE-LTSPICE_R0402
R_CAPACITOR: 15; ESP32_WROVER_EAGLE-LTSPICE_R0402
R_CHANGE: 10K; ESP32_WROVER_EAGLE-LTSPICE_R0402
R_CL1: 10K; ESP32_WROVER_EAGLE-LTSPICE_R0402
R_RESET: 10K; ESP32_WROVER_EAGLE-LTSPICE_R0402
SENSOR2: ESP32_WROVER_BME680_BME680; ESP32_WROVER_BME680_PSON80P300X300X100-8N
SJ1: SJ
TP1, TP2, TP3, TP4, TP5, TP6, TP7, TP8, TP9, TP10, TP11, TP12, TP13, TP14, TP15, TP16, TP17: TPTP20R; TP20R
U1: W25Q512JVEIQ; SON127P600X800X80-9N
U2: ESP32-C6-WROOM-1-N8; XCVR_ESP32-C6-WROOM-1-N8
U3: DS3231SN#; SOIC127P1032X265-16N
U4: MAX17048G+T10; SON50P200X200X80-9N

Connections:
3V3: C1_BAT2.1, C3.+, C9.1, D7.2 (ANODE), IC1.2 (VDD), IC4.5 (VOUT), J3.2, J4.P4 (VDD), Q2.3 (D), R1.1, R1_PINH1.2, R2_PINH1.2, R5.2, R6.2, R7.2, R8.2, R9.2, R10.2, R_BOOT.1, R_CHANGE.1, R_CL1.1, R_RESET.1, TP16.TP, U1.3 (!WP!(IO2)), U1.7 (!HOLD!/!RESET!(IO3)), U1.8 (VCC), U2.2 (3V3), U3.2 (VCC)
32KHZ: R2_PINH1.1, U2.9 (IO1), U3.1 (32KHZ)
DN: D1.4 (I/O2_2), J2.A7, J2.B7
DP: D1.6 (I/O1_2), J2.A6, J2.B6
EPD_3V3: C7.1, EPD_C5.1, J1.15, J1.16, L1.2, Q2.2 (S), TP17.TP
EPD_3V3_C: Q2.1 (G), R_CL1.2, TP13.TP, U2.18 (IO20)
EPD_BUSY: J1.9, TP9.TP, U2.26 (IO3)
EPD_CS: D6.1, J1.12, R9.1, TP10.TP, U2.11 (IO10)
EPD_DC: J1.11, TP11.TP, U2.5 (IO5)
EPD_RST: J1.10, TP12.TP, U2.21 (IO23)
FLASH_CS: D9.1, R5.1, U1.1 (!CS), U2.12 (IO11)
GDR: J1.2, Q3.1 (G), R4.1
GND: BOOT_BUTTON.1, BOOT_BUTTON.2, C1.2, C1_BAT.2, C1_BAT1.2, C1_BAT2.2, C2.2, C2_BAT.2, C3.-, C4_USB.2, C5.2, C5_USB.2, C6.2, C7.2, C8.2, C9.2, C10.2, C10_SUPERCAP.1, CHANGE_BUTTON.1, CHANGE_BUTTON.2, C_DELAY.2, D1.2 (GND), D3.1 (K), D6.2, D8.2, D9.2, D10.2, D11.2, D12.2, EPD_C1.2, EPD_C2.2, EPD_C5.2, EPD_C6.2, EPD_C7.2, EPD_C8.2, EPD_C9.2, EPD_C10.2, EPD_C11.2, EPD_C12.2, IC1.1 (VOUT), IC4.2 (VSS), J1.8, J1.17, J1.MP1, J1.MP2, J2.A1, J2.A12, J2.B1, J2.B12, J2.MP1, J2.MP2, J2.MP3, J2.MP4, J3.1, J4.G1 (GND_1), J4.G2 (GND_2), J4.G3 (GND_3), J4.G4 (GND_4), J4.P6 (VSS), MCP73831.2 (VSS), R1_PWRUSB.1, R2.1, R2-USB.2, R2-USB1.1, R2_BAT.1, R4.2, RESET_BUTTON.1, RESET_BUTTON.2, SENSOR2.1 (GND), SENSOR2.5 (SDO), SENSOR2.7 (GND), SJ1.1, TP4.TP, TP5.TP, U1.4 (GND), U1.9 (EXP), U2.1 (GND), U2.28 (GND), U2.29_1 (GND), U2.29_2 (GND), U2.29_3 (GND), U2.29_4 (GND), U2.29_5 (GND), U2.29_6 (GND), U2.29_7 (GND), U2.29_8 (GND), U2.29_9 (GND), U3.13 (GND), U4.1 (CTG), U4.4 (GND), U4.6 (QSTRT), U4.9 (EP)
GPIO8: R1.2, U2.10 (IO8)
I2C_PW: C1.1, C2.1, R1_PINH.2, R2-PINH.2, SENSOR2.2 (CSB), SENSOR2.6 (VDDIO), SENSOR2.8 (VDD), U2.17 (IO19)
INT_RTC: R1_PINH1.1, TP15.TP, U2.8 (IO0), U3.3 (SQW/!INT)
IO/BOOT: BOOT_BUTTON.3, BOOT_BUTTON.4, C6.1, R_BOOT.2, U2.15 (IO9)
IO/CHANGE: C10.1, CHANGE_BUTTON.3, CHANGE_BUTTON.4, R_CHANGE.2, U2.23 (IO15)
MISO: D12.1, J4.P7 (DAT0), R8.1, TP6.TP, U1.2 (DO(IO1)), U2.27 (IO2)
MOSI: D11.1, J1.14, J4.P3 (CMD), R7.1, TP7.TP, U1.5 (DI(IO0)), U2.7 (IO7)
unnamed: J2.B5, R2-USB.1
unnamed: MCP73831.1 (STAT), R1_BAT.1
unnamed: J2.A5, R2-USB1.2
unnamed: EPD_C12.1, J1.24
unnamed: EPD_C8.1, J1.20
unnamed: EPD_C10.1, J1.22
unnamed: EPD_C7.1, J1.19
unnamed: C1_BAT1.1, D2.1 (CATHODE), IC4.1 (VIN), IC4.3 (CE), Q1.2 (S)
unnamed: EPD_C6.1, J1.18
unnamed: C4_USB2.1, D3.2 (A), D4.1 (K)
unnamed: CHG_LED.C, R1_BAT.2
unnamed: MCP73831.5 (PROG), R2_BAT.2
unnamed: EPD_C1.1, J1.4
unnamed: EPD_C2.1, J1.5
unnamed: C_DELAY.1, IC1.5 (CT)
unnamed: D7.1 (CATHODE), R_CAPACITOR.2
PREVGH: D5.1 (K), EPD_C9.1, J1.21
PREVGL: D4.2 (A), EPD_C11.1, J1.23
RESE: J1.3, Q3.2 (S), R3.2
RESE': R2.2, R3.1, SJ1.2
RESET: C5.1, IC1.3 (GND), RESET_BUTTON.3, RESET_BUTTON.4, R_RESET.2, U2.3 (EN)
RTC_RST: U2.16 (IO18), U3.4 (!RST)
RX: TP2.TP, U2.24 (RXD0/GPIO17)
SCK: D10.1, J1.13, J4.P5 (CLK), R6.1, TP8.TP, U1.6 (CLK), U2.6 (IO6)
SCL: J3.4, R2-PINH.1, SENSOR2.4 (SCK), U2.20 (IO22), U3.16 (SCL), U4.7 (SCL)
SDA: J3.3, R1_PINH.1, SENSOR2.3 (SDI), U2.19 (IO21), U3.15 (SDA), U4.8 (SDA)
SRC: C4_USB2.2, D5.2 (A), L1.1, Q3.3 (D)
SS_SD: D8.1, J4.P2 (CD/DAT3), R10.1, U2.4 (IO4)
TX: TP1.TP, U2.25 (TXD0/GPIO16)
USB_D+: D1.1 (I/O1_1), U2.14 (IO13)
USB_D-: D1.3 (I/O2_1), U2.13 (IO12)
VBAT: C2_BAT.1, MCP73831.3 (VBAT), Q1.3 (D), TP3.TP, U4.2 (CELL), U4.3 (VDD)
VBUS: C1_BAT.1, C4_USB.1, C5_USB.1, CHG_LED.A, D1.5 (VBUS), D2.2 (ANODE), MCP73831.4 (VIN), PFMF.050.1.2, Q1.1 (G), R1_PWRUSB.2, TP14.TP
VRTC: C8.1, C10_SUPERCAP.2, R_CAPACITOR.1, U3.14 (VBAT)
VUSB: J2.A4, J2.A9, J2.B4, J2.B9, PFMF.050.1.1

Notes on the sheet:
USB C connector & ESD protection
LDO Voltage Regulator
SD Card
ESP32 C6
Display Type Selector
E-Paper Drive Circuit
Li-Po Battery Charging Controller
E-Paper Display Header
EPD Power
Environmental Sensor BME688
Voltage Supervisor + Reset & Boot / IO Button
Battery Charge Level
External NOR Flash 64MB
SPI ESD Protection Lines
Qwiic / Stemma QT
Test Pads
RTC Module DS3231SN

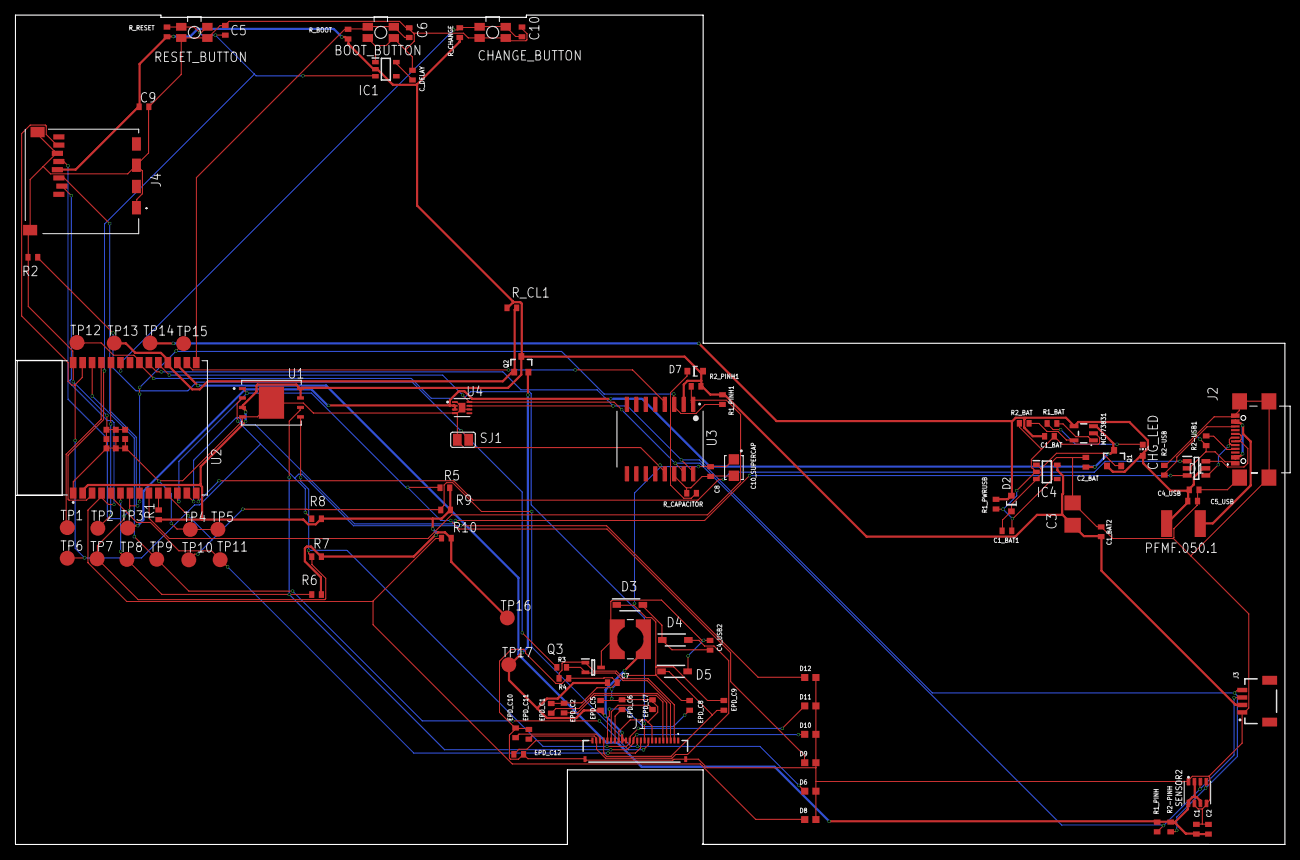
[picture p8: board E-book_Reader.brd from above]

Board: 2 copper layers, 170.2 x 111.2 mm, 103 parts (0 on the bottom side), 55 nets.

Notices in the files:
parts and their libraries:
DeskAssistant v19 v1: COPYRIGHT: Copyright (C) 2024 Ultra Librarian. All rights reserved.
